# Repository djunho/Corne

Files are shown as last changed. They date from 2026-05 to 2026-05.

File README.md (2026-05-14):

# Budget Wireless Corne Keyboard Build

A DIY wireless split keyboard based on the Corne layout, built for approximately $25 USD. This project uses a ProMicro clone with nrf52840 chip, making it a cost-effective alternative to traditional wireless split keyboard builds.

## Features
- Fully wireless using Bluetooth
- Split ergonomic design (Corne layout)
- Low profile design for portability
- Battery-powered with power switch
- ZMK firmware
- Estimated battery life: 1+ month

## Bill of Materials

| Component | Quantity | Cost (Euros) | Link |
|---|---|---|---|
| Controller boards (ProMicro nrf52840) | 2 | 7.06 | [AliExpress](https://a.aliexpress.com/_EIV3vwY) |
| Batteries | 4 | 11.54 | [AliExpress](https://pt.aliexpress.com/item/1005008790722153.html) |
| Mechanical Switches | 50 | 7.47 | [AliExpress](https://a.aliexpress.com/_EGhMxEC) |
| Diodes (1N4148) | 100 | 0.86 | [AliExpress](https://a.aliexpress.com/_EwZoG2G) |
| Slide Switches | 50 | 2.66 | [AliExpress](https://pt.aliexpress.com/item/1005010427557422.html) |
| 3D Printed Parts | Set | 1.80 | Files provided |

**Total Cost**: €31.39 (excluding wires and screws)
**LeftOvers**: 2 batteries, a lot of diodes and slide switch

## Current Keymap







## Build Instructions

### Prerequisites
- Basic soldering skills
- Access to a 3D printer
- Basic understanding of keyboard firmware

### Case Assembly
1. Print the case files (STL files provided in `3DFiles` directory)
2. Note: You may need to adjust the:
   - Battery compartment size
   - Slide switch holes

### Wiring
1. Wire switches in a matrix configuration
2. Connect diodes:
   - Direction matters (black line indicates cathode)
   - Use diode legs for the rows
   - Use separate wires for columns
3. Keep wiring clear of screw holes
4. Connect the battery:
   - GND to GND pin
   - Positive to one of the side legs on the slide switch
   - Middle pin of the slide switch to the RAW pin

### Pin Connections for Rows and Columns
The matrix configuration uses GPIO pins on the nRF52840 Pro Micro clone. Below are the connections:

pinout

#### How Rows and Columns Are Numbered

- **Rows**: Rows are always numbered from top to bottom on both halves.
- **Columns**: Columns are always numbered from left to right (as viewed from the back of the plate (where the wiring is done)).

⚠️ **Note**: If you accidentally solder the rows or columns to the wrong pins, you do not need to desolder. The mappings can be fixed in the firmware configuration files:
- `corne_left.overlay`: Defines rows and columns for the left half.
- `corne_right.overlay`: Defines rows and columns for the right half.
- `corne.dtsi`: Shared kscan settings (diode direction, etc.).

#### Left Half Pin Assignments
- **Rows (Connected to `row-gpios`)**:
  - Row 0: Pin 20
  - Row 1: Pin 19
  - Row 2: Pin 18
  - Row 3: Pin 15
- **Columns (Connected to `col-gpios`)**:
  - Column 0: Pin 2
  - Column 1: Pin 7
  - Column 2: Pin 6
  - Column 3: Pin 5
  - Column 4: Pin 4
  - Column 5: Pin 3

#### Right Half Pin Assignments
- **Rows (`row-gpios`)**:
  - Row 0: Pin 21
  - Row 1: Pin 20
  - Row 2: Pin 19
  - Row 3: Pin 18
- **Columns (`col-gpios`)**:
  - Column 0: Pin 3
  - Column 1: Pin 4
  - Column 2: Pin 5
  - Column 3: Pin 6
  - Column 4: Pin 7
  - Column 5: Pin 2

### Firmware Setup
This keyboard uses ZMK firmware. The left half acts as the main controller that connects to your device.

To flash the firmware:
1. Double press the reset button
2. Board will appear as mass storage device
3. Flash the appropriate firmware file

If you forgot the keyboard from your device and can't reconnect:
1. Flash the `settings_reset-nice_nano_v2-zmk.uf2` file
2. Reflash the regular firmware
3. Pair

## Repository Structure
```
├── .github/workflows/
│   └── build.yml
├── 3DFiles/
│   ├── STEP/
│   │   └── CorneSTEP.step
│   ├── STL/
│   │   ├── Case_Left.stl
│   │   ├── Case_Right.stl
│   │   └── PlateCorne.stl
├── config/
│   ├── boards/shields/corne/
│   │   ├── corne_left.conf
│   │   ├── corne_left.overlay
│   │   ├── corne_right.conf
│   │   ├── corne_right.overlay
│   │   ├── corne.conf
│   │   ├── corne.dtsi
│   │   ├── Kconfig.defconfig
│   │   └── Kconfig.shield
│   ├── corne.keymap
│   └── west.yml
├── firmware/
│   ├── corne_left-nice_nano_v2-zmk.uf2
│   ├── corne_right-nice_nano_v2-zmk.uf2
│   └── settings_reset-nice_nano_v2-zmk.uf2
└── zephyr/
    ├── module.yml
    └── build.yaml
```

## Known Issues
- Left side case may have warping issues if battery swells
- Slide switch holes may need adjustment based on your components

## Final result
im1
im3

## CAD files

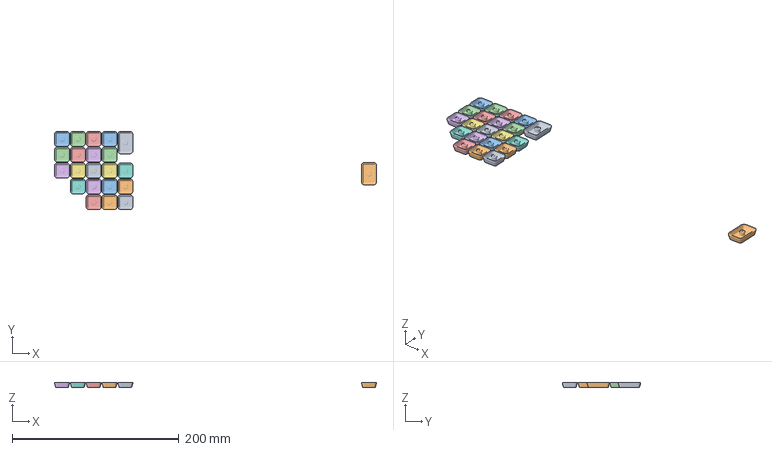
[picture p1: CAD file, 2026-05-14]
3DFiles/STL/Keycap.3mf
386.1 x 94.0 x 6.00 mm
Key 1.5U x 2

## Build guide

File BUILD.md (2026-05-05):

# Local Build

Builds ZMK firmware for this Corne config using upstream Zephyr SDK, no Nordic tooling.

## One-time setup

```fish
# System packages (Arch)
sudo pacman -S --needed gperf ccache

# Workspace + venv
mkdir -p ~/personal/zmk-workspace
cd ~/personal/zmk-workspace
python3 -m venv .venv
source .venv/bin/activate.fish
pip install --upgrade pip west

# Fetch ZMK + Zephyr sources (~1-2 GB)
west init -m https://github.com/zmkfirmware/zmk --mr main --mf app/west.yml
west update
west zephyr-export
west packages pip --install

# Zephyr SDK (ARM toolchain only, ~150 MB)
west sdk install -t arm-zephyr-eabi
```

## Per-session setup

Every new shell, before running any `west` command:

```fish
cd ~/personal/zmk-workspace
source .venv/bin/activate.fish
```

## Build

```fish
# Left half
west build -s zmk/app -d build/left -b nice_nano/nrf52840/zmk -- \
  -DSHIELD=corne_left \
  -DZMK_CONFIG=/home/djunho/personal/Corne/config

# Right half
west build -s zmk/app -d build/right -b nice_nano/nrf52840/zmk -- \
  -DSHIELD=corne_right \
  -DZMK_CONFIG=/home/djunho/personal/Corne/config

# Settings reset (only when re-pairing is needed)
west build -s zmk/app -d build/reset -b nice_nano/nrf52840/zmk -- \
  -DSHIELD=settings_reset \
  -DZMK_CONFIG=/home/djunho/personal/Corne/config
```

Output: `build/<side>/zephyr/zmk.uf2`.

## Iterate

Edit `config/corne.keymap`, then rerun the same `west build` — incremental rebuild takes seconds.

For a clean rebuild, add `-p always` or delete the build dir.

## Flash

1. Double-tap reset on the controller.
2. It mounts as USB mass storage.
3. Drag `build/<side>/zephyr/zmk.uf2` onto it.

---

## ZMK Studio

Studio is enabled by default on the right half (`CONFIG_ZMK_STUDIO=y` is set in `corne_right.conf`; the snippet is wired into CI via `build.yaml`). The right half is the BLE/USB central in this config — it's the side that connects to the host. For local builds, the snippet still has to be passed on the command line:

```fish
west build -p -s zmk/app -d build/right -b nice_nano/nrf52840/zmk \
  -S studio-rpc-usb-uart \
  -- -DSHIELD=corne_right \
     -DZMK_CONFIG=/home/djunho/personal/Corne/config
```

The left half and settings-reset builds are unchanged — Studio only runs on the central (right).

**Using it:** flash the right half, open https://zmk.studio, plug the USB cable into the **right** half, and press `lower + top-right key` to unlock — that combo is bound to `&studio_unlock` on the lower layer.

**If the build fails** with a linker "region overflow" error, flash is tight; disable unused features in `corne.conf` (RGB, display, etc. are already off).

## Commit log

2026-05-05 Move the USB to the right side
    it is easier on my current setup to use the USB on the right side
    add the dead tilde to easily add ãõ letters
2026-05-07 Add the dead_circumflex to insert ê
2026-05-08 Add the RIGHT_SHIFT and Print scren
2026-05-12 Move tab and add esc to left side to
2026-05-14 Update the README and add the 3D keycap file
    [Keycap.3mf]
2026-11-10 Fix BT/Adjust layer activation by replacing RALT with trans on raise thumb
    Holding both right thumb keys failed to reliably trigger the Adjust layer (layer 3)
    where Bluetooth controls (BT_CLR, BT_CLR_ALL) are mapped.
    Root cause:
    The outermost right thumb on the Raise layer (layer 2) was bound to &kp RALT (a
    leftover from the default ZMK template). When pressing both thumbs together, if
    mo 2 was triggered even milliseconds before mo 1, layer 2 intercepted the second
    thumb press as Right Alt instead of mo 1. Consequently, the tri-layer condition
    (if-layers = <1 2>) never activated layer 3, making Bluetooth reset and profile
    switching keys appear non-functional.
    Fix:
    Replaced &kp RALT with &t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
2026-11-12 feat: add PandaKB Corne V3 support and dual build matrix
    - Add configuration for PandaKB Corne V3 Choc PCB with 128x32 OLED and 27 RGB LEDs per half
    - Configure OLED status widgets for battery percentage, output/connection, and active layer
    - Decouple RGB from external power rail (CONFIG_ZMK_RGB_UNDERGLOW_EXT_POWER=n) to preserve OLED 3.3V power
    - Configure power management with 10-minute idle timeout and auto off/on for OLED and RGB
    - Add RGB controls to adjust layer in corne.keymap
    - Isolate existing handwired keyboard into custom shield 'corne_hw' with distinct Bluetooth name 'Corne HW'
    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
